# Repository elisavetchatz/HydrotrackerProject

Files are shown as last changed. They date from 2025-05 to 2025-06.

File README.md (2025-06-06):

# 💧 HydroTracker - Smart Water Cup Monitor for Cafés
<p align="center">
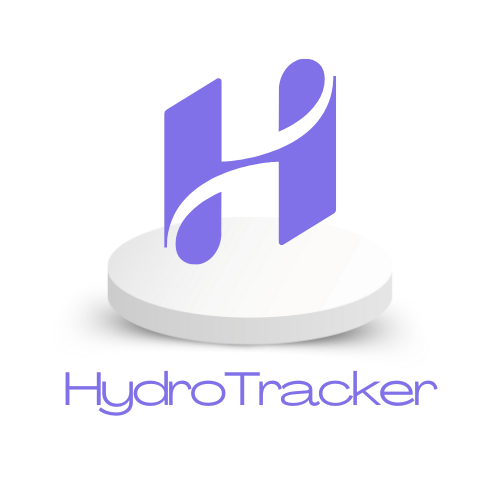
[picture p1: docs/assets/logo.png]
Hydrotracker Logo
  
</p>

HydroTracker is a smart hydration monitoring system originally designed to encourage water intake in work environments, now adapted into a **real-time service assistant** for **cafés**. It helps waitstaff **identify when customers' glasses are empty** and notifies them instantly—improving both **efficiency** and **customer experience**.

---

## 🚀 Project Overview

The idea began with a smart base (coaster) that uses a weight sensor to monitor the **daily water consumption** of users. Over time, the system evolved into a scalable solution for the **hospitality industry**, particularly cafés and restaurants.

Instead of waiters constantly checking glasses, HydroTracker lets them know **exactly when a refill is needed**, thanks to an intelligent network of coasters.

---

## 🎯 Use Case

> 💡 **Target audience**: Cafés and hospitality venues aiming to enhance service automation and hydration awareness.

Each coaster uses a **load cell sensor** connected to an **Arduino Uno** to detect changes in weight. When a glass is detected as **empty**, the node wirelessly transmits a message to a central receiver, which relays the update to a GUI system via serial communication.

---

## 🧠 Project Structure
```
📦 Hydrotracker
├── 📁 media # Videos, promo material, demo shots
│ ├── 📁 demo
│ └── 📁 promo
├── 📁 src # Main source code (Python, Arduino)
│ ├── 📁 data_processing
│ └── 📁 networking
├── 📁 docs # Documentation and reports
│ ├── 📁 assets
│   ├── 📁 gui_images
│   ├── 📁 load cell images
│   ├── 📁 setup_images
|   ├── 📁 business_images
│ └── 📁 report
├── 📁 3d_prints # 3D-printable .stl files
```
---

## 🛠️ Hardware Used

- 🧠 **Arduino Uno** – used in both nodes and central receiver  
- ⚖️ **3kg Load Cell** – detects weight of the glass  
- 🔊 **HX711 Amplifier Module** – reads and amplifies sensor output  
- 📡 **RFM22 ISM Transceiver Module** – enables node-to-node communication  
- 🧩 **Breadboard & Jumper Wires**  
- 🖨️ **3D-Printed Cup Base** – physically holds the sensor and glass  

---

## 📐 System Functionality

### 🧪 Sensor Logic

- Load cell detects the **weight** of the glass
- Readings are amplified and interpreted on the Arduino node
- If weight is below a threshold for a set time → considered **empty**

### 🔔 Notification & Communication

- Node sends signal via **ALOHA-style RF protocol**
- Central receiver aggregates messages and sends them to host PC
- The PC displays each node’s state (e.g., FULL / EMPTY) in a **GUI dashboard**
- Colored indicators show the status (e.g., 🟢 full, 🔴 empty)

---

## 📸 Media & Demo

The `media/` folder includes:
  
- 🎥 Demo video showing the system in action  
- 🖼️ Slides for presentations 
- 🎥 Promo video  

### ▶️ Watch Videos

🔧 Real-time demo of HydroTracker in action: [Demo Video](https://www.youtube.com/watch?v=DEMO_VIDEO_ID)

🎬 Promotional overview for cafés: [Promo Video](https://www.youtube.com/watch?v=PROMO_VIDEO_ID)

> Made with ☕ and 💡 by Team HydroTracker – Aristotle University of Thessaloniki

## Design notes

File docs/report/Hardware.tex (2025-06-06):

This section presents the hardware behind \textit{Hydrotracker}.  Below, we outline the materials used, the sensing principles, the mechanical base design and the full setup procedure.

\subsection{Materials Used}
The following materials were used in constructing a functional prototype of our system:
\begin{itemize}
\item \textbf{Arduino Uno board} – the central microcontroller used to read sensor data and handle communication logic.
\item \textbf{RFM22 ISM Transceiver module} – enables wireless communication between each coaster and a central receiver node.
\item \textbf{3kg Load Cell} – senses the weight of the glass placed on the coaster.
\item \textbf{HX711 Amplifier Module} – amplifies and digitizes the low-voltage analog signal from the load cell.
\item \textbf{3D-printed coaster base} – a custom mechanical housing for the sensor and load distribution.
\item \textbf{LED + 470 $\Omega $ resistor} – provides visual feedback for the taring process.
\item \textbf{Push button} – used to initiate the taring routine manually.
\end{itemize}
For the calibration procedure, we also used:
\begin{itemize}
\item A standard empty water glass.
\item A digital kitchen scale (±1 g precision).
\end{itemize}

\subsection{Load Cell}
The core of the system’s sensing capability lies in the load cell. A load cell is a transducer that converts the force (weight) applied to it into an electrical signal. When an object is placed on the load cell, it slightly deforms (Fig~\ref{fig:loadcell_deforms}). This deformation changes the electrical resistance inside the sensor (Fig~\ref{fig:loadcell-circuit-comparison}), which is then converted into a voltage signal proportional to the weight. This signal can be read by a microcontroller (e.g., Arduino) to determine how much the object weighs, up to a maximum of 3kg. In our case, the 3kg bar-type load cell is placed beneath a flat surface where the glass rests (Fig: \ref{fig:cup-base-views}) .

Since the voltage output from a load cell is very low (typically in the mV range), we use the HX711 module — a high-resolution 24-bit ADC amplifier — to digitize this signal and make it readable by the Arduino (Fig:~\ref{fig:system-setup-views}).
\begin{figure}[H]
    \centering
    \begin{subfigure}[b]{0.45\linewidth}
        \centering
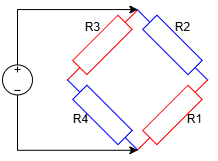
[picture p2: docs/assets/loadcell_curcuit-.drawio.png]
        
        \caption{Load cell circuit without weight}
        \label{fig:loadcell-weight}
    \end{subfigure}
    \hfill
    \begin{subfigure}[b]{0.45\linewidth}
        \centering
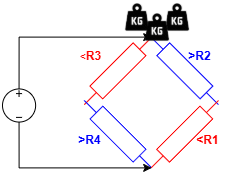
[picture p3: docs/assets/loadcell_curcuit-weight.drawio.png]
        
        \caption{Load cell circuit with weight}
        \label{fig:loadcell-noweight}
    \end{subfigure}
    \caption{Comparison of load cell circuit states: with and without applied weight}
    \label{fig:loadcell-circuit-comparison}
\end{figure}
\begin{figure}[H]
    \centering
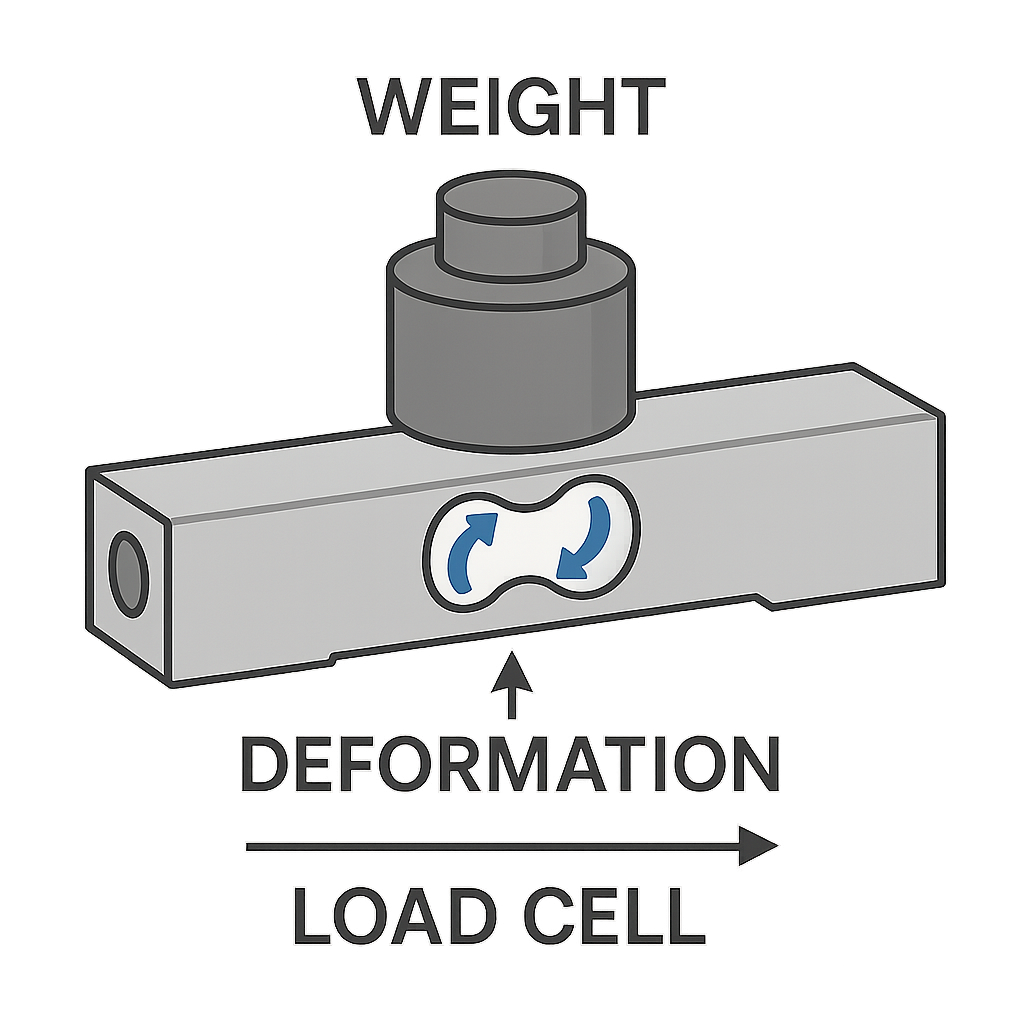
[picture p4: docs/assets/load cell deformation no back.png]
    
    \caption{Load cell slightly deformates when weight is placed on it}
    \label{fig:loadcell_deforms}
\end{figure}

\subsection{LED-Resistor-Button}
A small but essential subsystem in our design is composed of a push-button, an LED, and a 470 $\Omega$ resistor. This circuit provides user interaction and visual feedback during the taring process of the load cell.

When the system is powered on or reset, the load cell may carry residual mechanical offsets — due to the coaster’s base structure or the inherent weight of an empty cup. To correct this, we implement a manual taring mechanism, initiated by the user via the button.
The button is connected to a digital input pin on the Arduino. When pressed, it triggers the execution of a tare function. This function sets the current output of the HX711 as the new zero reference, assuming the only weight applied is that of the empty cup.

To indicate the progress of this operation, an \textit{LED} is also included. It is connected in series with a 470 $\Omega$ resistor to limit current and is wired to another digital pin configured as an output. When taring is in progress, the LED turns on. Once the process is complete, the LED switches off, notifying the user that the system is ready for use.

\subsection{3D printed cup base}
The physical housing of the coaster is critical to ensure consistent force transfer from the glass to the sensor. Our design consists of two %interlocking 
3D-printed shells (top and bottom). The upper platform is where the base of the glass rests, designed to %evenly distribute the load
concentrate the load to the edge of the load cell for maximum accuracy.
This geometry ensures that vertical force is transmitted directly through the center of the load cell, minimizing measurement noise due to tilting or off-center loading. Figures \ref{fig:base-bottom} and \ref{fig:base-side} show a bottom and a side view of the base design, with the load cell integrated.

\begin{figure}[H]
    \centering
    \begin{subfigure}[b]{0.45\linewidth}
        \centering
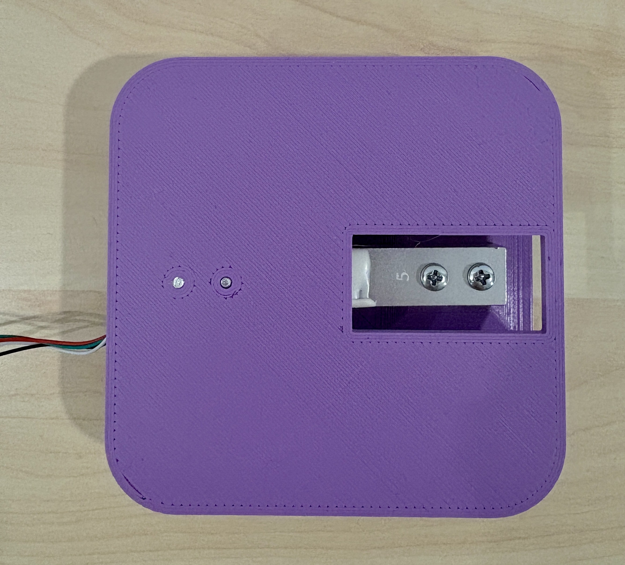
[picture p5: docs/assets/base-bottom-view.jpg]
        
        \caption{Bottom view of the cup base}
        \label{fig:base-bottom}
    \end{subfigure}
    \hfill
    \begin{subfigure}[b]{0.45\linewidth}
        \centering
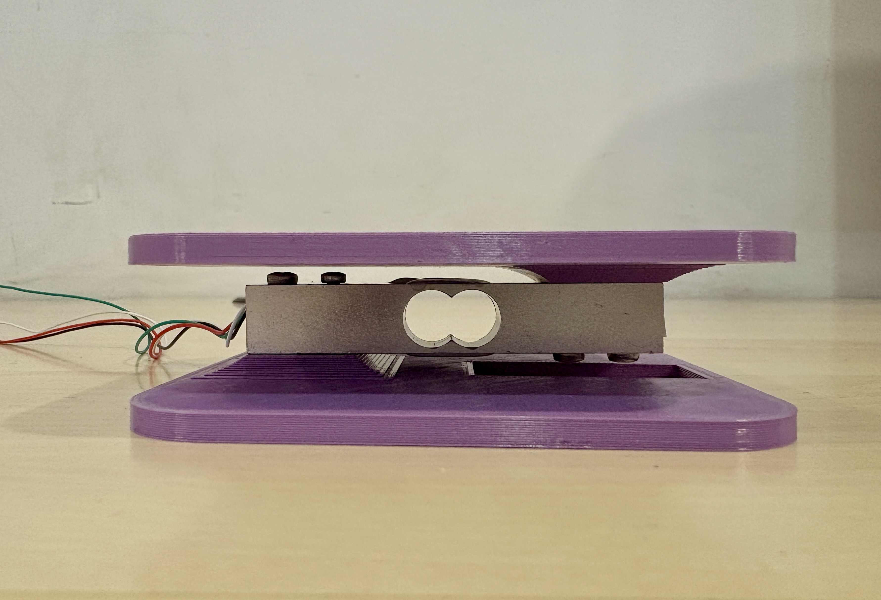
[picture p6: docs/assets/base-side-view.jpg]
        
        \caption{Side view of the cup base}
        \label{fig:base-side}
    \end{subfigure}
    \caption{3D-printed coaster base: structural views}
    \label{fig:cup-base-views}
\end{figure}

\subsection{Set-up}
The system setup consists of four primary components working together: the mechanical base, the sensing subsystem, the user interface circuit, and the wireless communication module.

The load cell is mounted securely within the custom-designed 3D-printed base. Its output is routed to the HX711 amplifier module, which is responsible for digitizing the analog signal. The HX711 is then connected to the Arduino Uno, allowing the microcontroller to receive precise weight data.

\begin{figure}[H]
    \centering
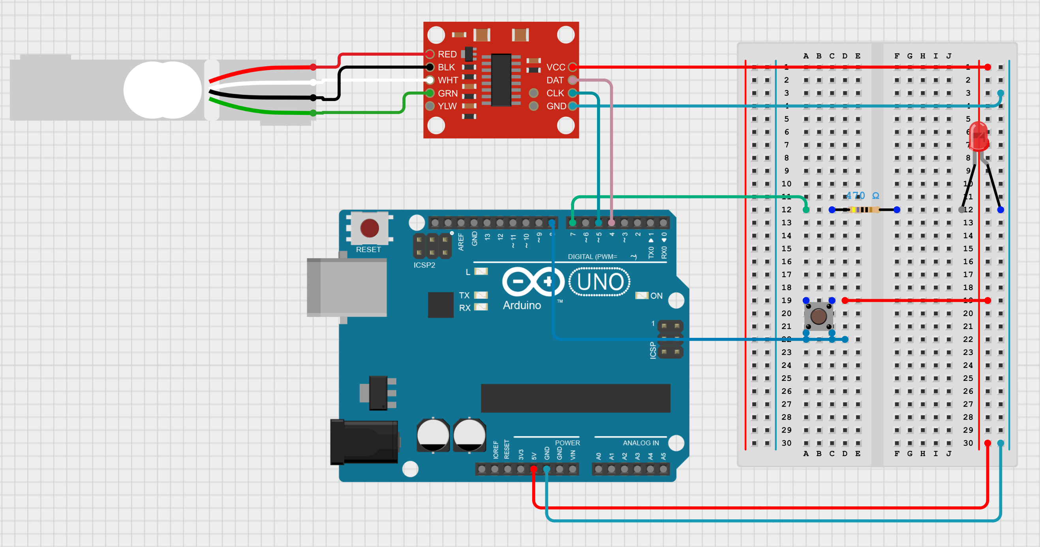
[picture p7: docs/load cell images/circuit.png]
    
    \caption{System connection diagram}
    \label{fig:circuit}
\end{figure}

On the breadboard, the push-button and LED are in series with the 470 $\Omega$ resistor. The button is connected to a digital input pin and is used to trigger the taring process, while the LED is connected to an output pin and provides visual feedback indicating the system’s readiness.

To enable communication between multiple coaster nodes and a central monitoring station, the system incorporates an RFM22 wireless transceiver, connected to the Arduino via SPI. This module transmits each node’s state information (\texttt{EMPTY}, \texttt{NOTEMPTY}, \texttt{NOTEXIST}) to a receiver, which updates the graphical user interface accordingly.

The full connection diagram of the system is displayed on Figure \ref{fig:circuit}

\begin{figure}[H]
    \centering
    \begin{subfigure}[b]{0.45\linewidth}
        \centering
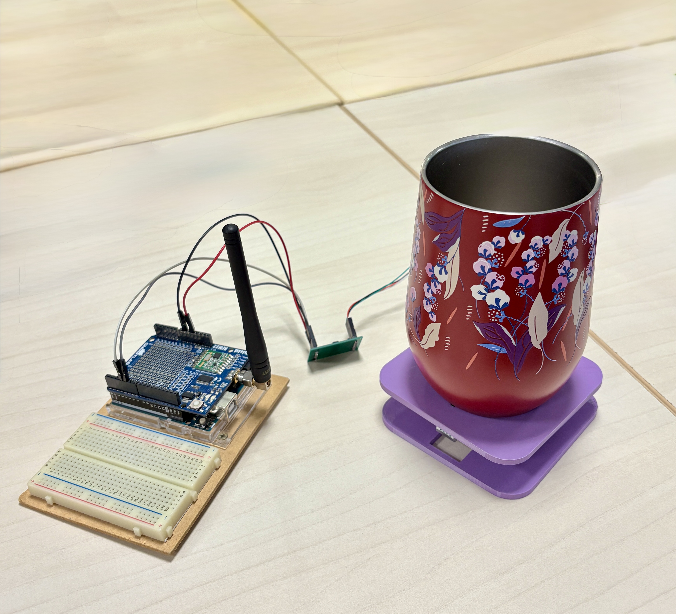
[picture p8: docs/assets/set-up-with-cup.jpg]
        
        \caption{System setup with the cup placed on the coaster}
        \label{fig:setup-with-cup}
    \end{subfigure}
    \hfill
    \begin{subfigure}[b]{0.45\linewidth}
        \centering
        
        \caption{System setup without the cup}
        \label{fig:setup-without-cup}
    \end{subfigure}
    \caption{Smart coaster hardware setup: with and without the cup}
    \label{fig:system-setup-views}
\end{figure}

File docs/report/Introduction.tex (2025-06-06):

The goal of this assignment is to design and implement a network-based application that provides real-time monitoring and communication functionalities. The system must support node-to-node interaction, dynamic data handling, and practical deployment in a real-world environment.

\subsection{HydroTracker}

\textit{HydroTracker} is a smart service-assistance system designed for use in cafés and similar settings. Its core concept is based on a distributed network of coaster-shaped sensing nodes that monitor water glass levels.

Each coaster node integrates a load cell — a force sensor that varies resistance with applied weight — connected to an Arduino Uno microcontroller. These microcontrollers act as \textbf{transmitters}, processing the weight data locally and sending it wirelessly to a central \textbf{receiver node}, also built on an Arduino. The receiver collects the measurements from all transmitters and forwards them via serial communication to a host computer. There, a data processing application interprets the input and presents it in a graphical user interface, clearly displaying the fill level of each glass using intuitive color indicators.

\begin{figure}[H]
    \centering
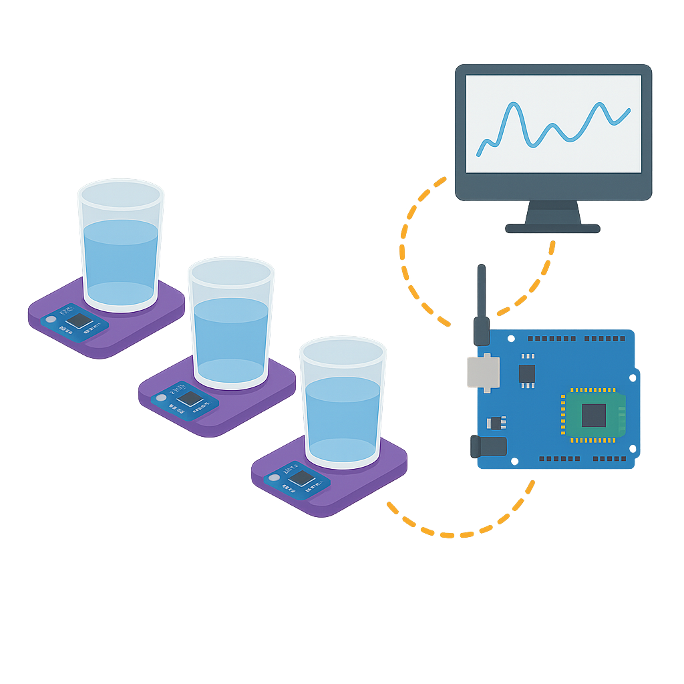
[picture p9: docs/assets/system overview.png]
    
  \caption{HydroTracker System Overview}
  \label{fig:hydrotracker_architecture}
\end{figure}

The main purpose of HydroTracker is to help waitstaff monitor tables efficiently, without having to constantly check every glass manually. This reduces unnecessary effort, streamlines service flow, and enhances the overall customer experience.

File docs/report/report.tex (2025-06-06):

\documentclass{article}
\usepackage{graphicx}
\usepackage[style=ieee]{biblatex} % Set the reference style to IEEE
\usepackage{xcolor}
\usepackage{hyperref}
\usepackage{titletoc}

\usepackage{array} % For customizing the table
\usepackage{booktabs} % For better quality horizontal lines
\usepackage{graphicx} % Package for including images
\usepackage{float}
\usepackage{subcaption}

% Define margins
\usepackage[margin=1in]{geometry}

\usepackage{listings}
\usepackage{xcolor}

\lstset{
  basicstyle=\ttfamily\footnotesize,
  numbers=left,
  numberstyle=\tiny\color{gray},
  stepnumber=1,
  numbersep=5pt,
  backgroundcolor=\color{white},
  showspaces=false,
  showstringspaces=false,
  showtabs=false,
  frame=single,
  rulecolor=\color{black},
  tabsize=2,
  captionpos=b,
  breaklines=true,
  breakatwhitespace=false,
  keywordstyle=\color{blue},
  commentstyle=\color{gray},
  stringstyle=\color{orange},
}

\begin{document}

\begin{titlepage}
    \centering
    % AUTH University logo
    
    \par\vspace{2cm}

    % University name and course details
    {\Large \textbf{Aristotle University of Thessaloniki} \par}
    \vspace{0.5cm}
    {\large School of Electrical and Computer Engineering\par}
    {\large 099 - Applications of Telecommunication Devices\par}
    \vspace{3cm}

    % Project details
    {\Large \textbf{HydroTracker} \par}
    {\large Smart cup base network \par}
    { A wireless communication system designed to \\ detect and report the water level in a glass in real time \par}
    \vspace{3cm}

    % Team members
    {\large \textbf{Team} \par}
    \vspace{0.5cm}
    \begin{tabular}{ll}
    10670 & Maria Charisi \\
    10792 & Elisavet Chatzikyrka \\
    10674 & Ioannis Lolos\\
    10866 & Maria Sotiria Kostomanolaki \\
    \end{tabular}
    \par\vspace{3cm}

    % Date
    {\today \par}

\end{titlepage}

\tableofcontents 

\newpage 

% Document content
\section{Introduction}
\input{Introduction}

\newpage
\section{Hardware}
\input{Hardware}

\section{Networking}
\input{Networking}

\section{Data Processing and User Interface}
\input{DataProcessing}

\section{Business Model}
\input{BussinessModel}

\section{Conclusion}
\input{Conclusion}

\begin{thebibliography}{9}

\bibitem{hx711-youtube}
HX711 with a Four Wire Load Cell and Arduino | Step by Step Guide., 
\textit{YouTube video}, accessed May 2025. \\
\url{https://www.youtube.com/watch?v=sxzoAGf1kOo}

\bibitem{hx711-github}
$HX711\_ADC$, 
\textit{GitHub Repository}, accessed May 2025. \\
\url{https://github.com/olkal/HX711_ADC}

\bibitem{prof-code}
Lab Starter Code – Applications of Telecommunication Devices, 
provided by Prof. [Dimitriou Antonios], AUTH, Spring 2025.

\end{thebibliography}
\textbf{Project Repository:} \url{https://github.com/elisavetchatz/HydrotrackerProject}
\end{document}

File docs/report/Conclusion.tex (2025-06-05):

HydroTracker is a smart coaster system designed to monitor the fill level of glasses in real time and notify staff when service is needed. By combining load cell sensors, Arduino-based wireless nodes, and a graphical user interface, the system offers an efficient and user-friendly solution for service environments.The system performs reliably, offering accurate state detection and real-time visual feedback. 

Ideally, HydroTracker would be implemented as a fully integrated, wireless, and portable smart device. Instead of relying on a separate Arduino board and wired modules, each coaster node would embed a compact microcontroller (e.g., ESP32) directly into its body, along with a thin rechargeable battery and low-power management for long-term operation. This integration would eliminate external components and wiring, resulting in a cleaner, more robust design. Additionally, wireless connectivity such as Wi-Fi or Bluetooth Low Energy (BLE) could support seamless data transmission and real-time monitoring across larger spaces or cloud services. Lastly, the ideal sensor for this setup would be a thinner load cell, helping reduce the overall size and visual presence of the coaster, making it more discreet, user-friendly, and visually appealing.

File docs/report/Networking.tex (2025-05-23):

The HydroTracker system utilizes a custom wireless communication network built on \textit{Arduino microcontrollers} and \textit{RFM22 ISM-band transceivers}. 
Each coaster-shaped transmitter node, associated with a water glass, continuously monitors weight data using an \textit{HX711 load cell}. 
This data is processed locally and transmitted wirelessly to a central receiver node. 
The receiver then relays this information to a host computer for real-time visualization.

In this section, we will describe the code implementation for both the receiver and transmitter nodes, and explain the wireless communication protocol used in the system.

\subsection{Wireless Communication Protocol}

The system uses the RF22Router library, which provides a basic routing layer over the RFM22 radio transceivers. 
Each transmitter node and the receiver are assigned unique addresses, enabling reliable routing and identification of messages. 
Communication operates on the \textit{444.0 MHz} frequency using \textit{Gaussian Frequency Shift Keying (GFSK)} modulation with a data rate of \textit{125 kbps}.

To manage potential transmission collisions, the system implements a simplified \textit{ALOHA protocol} in the transmitter code:
\begin{itemize}
    \item Each transmitter sends a data packet using \texttt{sendtoWait()}, which waits for an acknowledgment from the receiver.
    \item If the acknowledgment is not received (indicating a failed or collided transmission), the transmitter waits for a \textit{random backoff delay} between 200 ms and 3000 ms before retrying.
    \item This randomized retransmission reduces the chance of repeated collisions when multiple nodes attempt to send data at the same time.
\end{itemize}

\begin{lstlisting}[language=C++, caption={ALOHA protocol implementation in the transmitter}]
bool successful_packet = false;
while (!successful_packet){

    if (rf22.sendtoWait(data_send, msg_len, DESTINATION_ADDRESS) != RF22_ROUTER_ERROR_NONE)
    {
        Serial.print("Sending: ");
        Serial.println(data_read);
        long randNumber = random(200, 3000)
        delay(randNumber);
    }
    else
    {
        successful_packet = true;
        Serial.println("Packet sent successfully!");
    }
}
\end{lstlisting}

This approach is particularly suited for low-traffic, sporadic communication systems, such as HydroTracker, where nodes send updates only when state changes are detected. 

\subsection{Receiver}
The receiver node is responsible for collecting data from multiple transmitters and relaying it to the host computer.
Its primary tasks are:

\begin{itemize}
    \item Initialize the RF22 radio module.
    \item Define known routes to each transmitter node.
    \item Continuously receive incoming data packets.
    \item Format the received data as \texttt{Node <node\_id> - State: <state>}.
    \item Forward the formatted data to the host computer via serial communication for further processing and display.
\end{itemize}

\subsection{Transmitters}
Each transmitter node is responsible for monitoring the weight of an individual glass and wirelessly reporting its status to the receiver node.
The transmitter code performs the following key functions:

\begin{enumerate}
    \item \textbf{Load cell initialization:}{
    Each transmitter uses an \textit{HX711} load cell amplifier to measure the weight of the glass. 
    The initialization of the load cell is performed during the \texttt{setup()} function.
    \begin{itemize}
        \item The data and clock pins of the HX711 are defined and used to create a \texttt{HX711\_ADC} object named \texttt{LoadCell}.
        \item The \texttt{LoadCell.begin()} function initializes the connection to the sensor.
        \item The \texttt{LoadCell.start(2000, tare)} function starts the sensor with a 2-second warm-up period and performs a tare (zeroing) operation.
        \item If initialization is successful, a calibration factor is applied using \texttt{LoadCell.setCalFactor()}. This factor is determined empirically through a calibration process and converts raw readings into meaningful weight units.
    \end{itemize}

    \begin{lstlisting}[language=C++, caption={Load cell initialization}]
    #include <HX711_ADC.h>

    const int HX711_DOUT = 4; // HX711 data pin
    const int HX711_SCK = 5;  // HX711 clock pin
    HX711_ADC LoadCell(HX711_DOUT, HX711_SCK);

    void setup() {
        LoadCell.begin();
        bool tare = true;
        LoadCell.start(2000, tare);

        if (LoadCell.getTareTimeoutFlag() || LoadCell.getSignalTimeoutFlag())
        {
            Serial.println("HX711 not found. Check wiring and pin designations.");
            while (1);
        }
        else
        {
            float calibrationFactor = 448.31; // Calibration Factor
            LoadCell.setCalFactor(calibrationFactor);
        }
    }
    \end{lstlisting}}

    \item \textbf{Weight monitoring and State classification:}{
    The function \texttt{getCurrentState()} is responsible for determining the current state of the transmitter node based on the measured weight. 
    It uses predefined threshold values to classify the state of the glass as either \texttt{NOTEXIST}, \texttt{EMPTY}, or \texttt{FULL}.

    Before classification, the function ensures that the weight reading is stable by repeatedly sampling the load cell until the weight change falls within a ±1g margin.
    This is necessary because, after a change in weight, the load cell may take a few seconds to stabilize.

    The thresholds are defined based on the fact that the load cell is tared with an empty glass placed on it. 
    This implies the following:
    \begin{itemize}
        \item \textbf{Values around 0g:} The glass is empty.
        \item \textbf{Negative values:} The glass does not exist.
        \item \textbf{Positive values:} The glass contains some amount of water.
    \end{itemize}

    \begin{lstlisting}[language=C++, caption={Weight monitoring and state classification}]
    const float NOTEXIST_THRESHOLD = -20.0; // Threshold for no existence
    const float EMPTY_THRESHOLD = 50.0;    // Threshold for empty

    state getCurrentState(){

        LoadCell.update();
        float currentWeight = LoadCell.getData();

        while (1)
        {
            delay(1000);
            LoadCell.update();
            float weight = LoadCell.getData();

            if (weight < currentWeight + 1.0 && weight > currentWeight - 1.0)
            {
                currentWeight = weight;
                break; // Exit the loop if weight is stable
            }

            currentWeight = weight;
        }

        if (currentWeight < NOTEXIST_THRESHOLD) return NOTEXIST;
        else if (currentWeight < EMPTY_THRESHOLD) return EMPTY;
        else if (currentWeight >= EMPTY_THRESHOLD) return NOTEMPTY;
    }
    \end{lstlisting}}

    \item \textbf{Tare function:}{
    The user can manually tare the load cell by pressing a button connected to a digital pin.
    The tare function is triggered when the button is pressed, and it sets the current weight reading to zero.
    This is useful for recalibrating the load cell when a new glass is placed on it.
    
    \begin{lstlisting}[language=C++, caption={Tare function}]
    if (digitalRead(TARE_BUTTON_PIN) == HIGH)
    {
        Serial.println("Tare button pressed. Taring...");
        digitalWrite(LED_PIN, HIGH);
        LoadCell.tare();
        digitalWrite(LED_PIN, LOW);
    }
    \end{lstlisting}}

    \item \textbf{Data transmission:}{
    The packet transmission is handled by the \texttt{sendPacket()} function. 
    This function formats the current state as a string (e.g., \texttt{"EMPTY"}, \texttt{NOTEMPTY"}, \texttt{"NOTEXIST"}) and attempts to transmit it to the receiver node using the \textit{ALOHA protocol}.

    To optimize network usage and conserve energy, the transmitter only sends a packet when a change in the glass state is detected.
    To achieve this, in the \texttt{loop()} function, the following steps are performed:
    \begin{itemize}
        \item The transmitter maintains a record of the \texttt{previousState}.
        \item On each loop iteration, the current state is determined using \texttt{getCurrentState()}.
        \item If the state is unchanged, no packet is sent.
        \item If the state changes, the new state is sent using \texttt{sendPacket()} and \texttt{previousState} is updated accordingly.
    \end{itemize}

    \begin{lstlisting}[language=C++, caption={Packet transmission on state change}]
    state currentState = getCurrentState();

    if (currentState != previousState)
    {
        sendPacket(currentState);
        previousState = currentState;
    }
    else
    {
        Serial.print("State unchanged: ");
        Serial.println(stateToString(currentState));
    }
    \end{lstlisting}}
\end{enumerate}

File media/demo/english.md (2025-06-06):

## Demo Voiceover in English

At first, we see the coaster from a side view.
It consists of two 3D-printed bases, which enclose a variable metallic resistance — a load cell.

Placing it in a horizontal position, we observe the surface where the glass is placed.

Then, we take a look at the full wiring of the sensor.

First, we have the HX711 amplifier, which digitizes the analog signal from the load cell.
Next, we see the breadboard, where our microcontroller is connected — in this case, an Arduino Uno.

On the breadboard, there is an LED with a 470-ohm resistor and a button, used to automate the taring process.

The Arduino is also connected to an RF22 module, enabling wireless communication between the coaster nodes.

When the sensor is initialized, we observe weight measurements on the serial monitor.
Since the coaster is empty, these values fluctuate close to zero, and the default state displayed is "EMPTY".

We now place an empty glass on the coaster, with the purpose of performing a tare — zeroing the sensor using this specific glass as a tare weight.

We observe that the weight reading increases significantly — as expected.
At the same time, the state of the glass changes from "EMPTY" to "NOT EMPTY".

Due to this change, the transmitter sends a packet to the receiver, which then updates the GUI at the top right of the screen.

In order for the coaster to function correctly, the taring process must be completed first — as mentioned earlier.
We press the button to initiate the process. The LED turns on, and once the taring is complete, it turns off — indicating to the user that the system is ready for use.

After the taring, we observe on the GUI that the node now shows the correct state — "EMPTY".

Now, we fill the glass with water, and as expected, we see an immediate increase in the sensor's weight reading.

As soon as this reading exceeds a predefined threshold, the coaster’s state changes.
A new ALOHA packet is sent from the transmitter to the receiver, and the GUI updates automatically.

We now expand the network by adding another node — that is, a second glass.
This addition is immediately reflected in the GUI, as a new node label appears.

We fill the second glass with water, and observe the change in status from "EMPTY" to "NOT EMPTY".

Next, we remove the glass from the base. After a short delay, the state changes to "NOT EXIST".
During this time, the algorithm checks if the current state is significantly different from the previous ones, ensuring the change is valid before sending the update packet.

It is worth noting that the green color on the GUI indicates that the glass is not empty, and the waitress does not need to intervene.

In contrast, when the color turns red, it signals that it is time to serve the customer.

Continuing, we place the glass back on the base, and the state returns to "NOT EMPTY".

Finally, we lift the glass from the second node, which was previously full.
After consuming its contents, we place the now empty glass back on the coaster.

As expected, the coaster detects the change, the node sends a new packet, and the waitress sees on the GUI that the node has turned red, signaling that the glass is empty and the customer needs service.

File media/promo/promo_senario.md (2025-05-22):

# HydroTracker – Promo Video Scenario

## Title
**HydroTracker – Never let a glass go empty again!**

## Overview
A chaotic day in a busy café, with a frantic waiter running around trying to keep up with empty glasses, turns into a smooth and smart customer service experience thanks to **HydroTracker** – the smart coaster that alerts you when a glass is empty.

---

## Scenes & Shooting Directions

### Scene 1 – “The Chaos”

**Location:** Café with tables, customers, waiter behind the bar  
**Duration:** ~30–40 seconds  

#### Shot 1: Wide
- Waiter is behind the bar, stressed and sweaty.
- He nervously scans the tables and moves his head back and forth to ensure every water cup is full.
- Voice-over: *"In a world where every drop counts..."*

#### Shot 2: Close-Up + Slow Motion
- A customer finishes their last sip in slow motion.
- Close-up on the customer swallowing the final gulp.
- Loud *"gulp"* sound effect.
- Cut to waiter’s eyes—sharp focus and dramatic zoom as he jolts upright like an alarm just went off.

#### Shot 3: Chaos Montage
- The waiter rushes across the café.
- Spills a tray, bumps into chairs.
- Split screen: another customer finishes their water.
- The waiter is overwhelmed, always one step behind.

#### Shot 4: Time Lapse
- Fast-forward montage of the waiter running non-stop.
- Final shot: he collapses in a chair, exhausted. All glasses are still empty.

---

### Scene 2 – “The Solution”

**Location:** Same café  
**Duration:** ~30 seconds  

#### Shot 5: Logo Intro
- HydroTracker (logo) appears.
- Slogan: *"The smart coaster that does the job for you!"*

#### Shot 6: Calm Bartender
- Same waiter, now relaxed, sitting behind the bar with a coffee.
- He watches a screen (laptop) with the GUI.
- All table indicators are **green**.

#### Shot 7: Sensor Trigger
- A customer finishes their water → GUI changes from green to red.
- “Ding” sound effect plays and LED light turns red.

#### Shot 8: Chill Refill
- Waiter gets up **calmly**, grabs a water jug.
- Walks to the table **in style**.

#### Shot 9: Interaction
- The customer thanks him.
- He gives a thumbs-up to the camera.

#### Shot 10: Outro
- Logo + final slogan:
  > **HydroTracker – Never let a glass go empty again!**

---

## Equipment & Props

### Equipment
- Microphone Despoinas
- Laptop to display GUI demo

### Props
- Clear water glasses
- Water jug or bottle
- Waiter apron
- HydroTracker prototype

---

## Sound & Music

- **Scene 1:** humorous music (espresso machiatto) or under pressure
- **Scene 2:** calm music
- **Sound Effects (SFX):** "gulp", "ding", footsteps, spills

---

## Filming Checklist

- Set up café environment
- Film “chaos” sequence
- Film calm scene with HydroTracker
- Record GUI state transitions (green to red)
- Add voiceover, music, and slogan
- Final edit with logo and transitions

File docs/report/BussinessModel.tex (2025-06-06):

This section presents the proposed business model for introducing \textit{HydroTracker} to the market as a product for the service industry. It includes a Business Canvas that outlines the value proposition, key cost and revenue activities, as well as a demonstration video showing the functionality of the \textit{HydroTracker}, and a promotional video.

\subsection{Business Canvas}
The \textit{HydroTracker} is an innovative water level monitoring system designed to improve customer experience and support staff efficiency in the service industry. It enables quick and efficient refills of water, helping staff respond quickly to customer needs and avoid missed requests during peak hours. This not only improves the overall customer experience, but also supports better task coordination among staff, resulting in a less stressful work environment.

What makes \textit{HydroTracker} stand out is its ability to integrate smoothly into existing service processes. Its compatibility with PDA order management systems enhances operational efficiency while reinforcing the business’s professional image. 

The primary costs in this business model include the sourcing of sensors and micro-controllers, prototype production, software development, and promotional activities.

The target market consists of approximately 110,000 service industry businesses in Greece, with early adopters being futuristic and luxury venues aiming for premium service. In the future, cost reductions will allow expansion to small and medium-sized business owners, as well as exports. Additionally, thanks to its modular and scalable architecture, \textit{HydroTracker} can be extended beyond cafés—such as into office spaces, hospitals, or co-working environments—offering smart hydration 

\begin{figure}[H]
    \centering
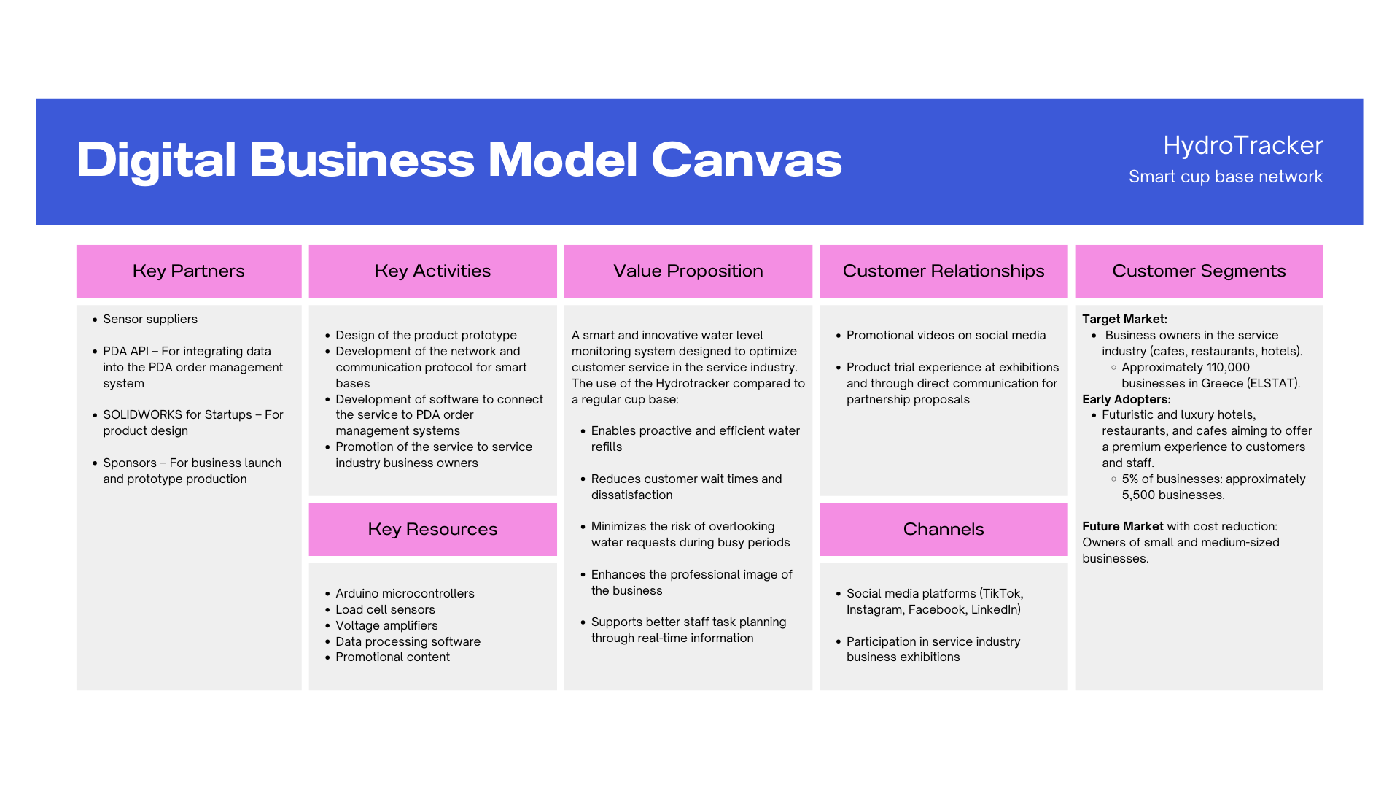
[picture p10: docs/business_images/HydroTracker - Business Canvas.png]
    
    \caption{\textit{HydtroTracker} Business Canvas}
    \label{fig:enter-label}
\end{figure}

\subsection{Demonstration Video}
A demonstration video showcasing the functionality of the \textit{HydroTracker} is available \href{https://youtu.be/DthdfglUvXY?si=8oIWrk7Wovcrerfg}{here}. The video presents how the system operates in a real-world setting, highlighting its key features.

\subsection{Promotional Video}
A promotional video has been created to highlight the key benefits of the HydroTracker for potential customers and investors. The video is available \href{https://www.youtube.com/watch?v=uHeOhnM9qX0}{here}.

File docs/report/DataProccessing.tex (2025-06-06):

In this section, we describe the software architecture of the HydroTracker system, which monitors the status of multiple sensor nodes in real time. The application is composed of two primary components:
\begin{itemize}
    \item A background thread that reads and processes incoming serial data.
    \item A user interface that visualizes node states in real-time using colored labels.
\end{itemize}

\subsection{Reading from the Serial}

Serial communication is handled by the \texttt{SerialReaderThread} class, which operates in a separate background thread to prevent GUI blocking. Its main functionality is found in the \texttt{read\_serial()} method. The thread checks if data is available (\texttt{in\_waiting > 0}), reads and decodes the incoming string, and logs it. If the message follows the format \texttt{Node<id> - State:<STATE>}, the node ID and state are extracted. This call delegates the responsibility of updating the GUI to the main application \texttt{HydrotrackerMonitor}.

\subsection{Data Processing}
Once a valid line is received, it is parsed into two key components:
\begin{itemize}
    \item \texttt{node\_id}: the identifier of the node
    \item \texttt{state}: the reported status (e.g., "EMPTY", "NOTEMPTY", or "NOTEXIST")
\end{itemize}
After extracting these, the GUI is updated only if the state has changed. Each node has an entry in a dictionary \texttt{node\_states} that keeps track of its most recent state. This structure enables efficient state tracking and minimizes unnecessary GUI updates.

The following snippet illustrates the logic used to parse incoming serial messages and trigger GUI updates accordingly:
\begin{lstlisting}[language=Python, caption={Serial data parsing and GUI update}]
if self.serial_conn.in_waiting > 0:
    # Read incoming serial line
    line = self.serial_conn.readline().decode('utf-8').strip()
    
    # Check if it matches the expected format
    if line.startswith("Node") and " - State: " in line:
        before, _, after = line.partition(" - State:")
        node_id_str = before.replace("Node", "").strip()
        state = after.strip()
        
        # If valid node ID, update the GUI
        if node_id_str.isdigit():
            self.app.update_node_state(int(node_id_str), state)
\end{lstlisting}

\subsection{User Interface}
The GUI is created using Python's \texttt{tkinter} module and is managed by the \texttt{HydrotrackerMonitor} class. For each detected node, a label is dynamically added with the method \texttt{create\_gui\_label(node\_id)}. Each label changes its color and text based on the node's current state. This is managed in the \texttt{update\_gui\_loop()} method, which periodically refreshes the display.
The following listing illustrates this logic:

\begin{lstlisting}[language=Python, caption={GUI update and label coloring based on node state}]
def update_gui_loop(self):
    for node_id, state in self.node_states.items():
        label = self.labels[node_id]
        label.config(text=f"Node {node_id}: {state}") 

        if state == "EMPTY":
            label.config(bg="#e74c3c", fg="white")  # red
        elif state == "NOTEMPTY":
            label.config(bg="#2ecc71", fg="white")  # green
        elif state == "NOTEXIST":
            label.config(bg="#7f8c8d", fg="white")  # gray
        else:
            label.config(bg="#bdc3c7", fg="black")  # default

    self.root.after(UPDATE_INTERVAL, self.update_gui_loop)
\end{lstlisting}

The following figures present the graphical user interface (GUI) of the HydroTracker system during runtime. The interface dynamically updates based on real-time input from the sensor nodes. Each label represents a specific node and changes color and text to reflect its current state. The visual encoding allows the user to quickly identify which tables require attention.

\begin{figure}[H]
    \centering
    \begin{subfigure}[b]{0.4\linewidth}
        \centering
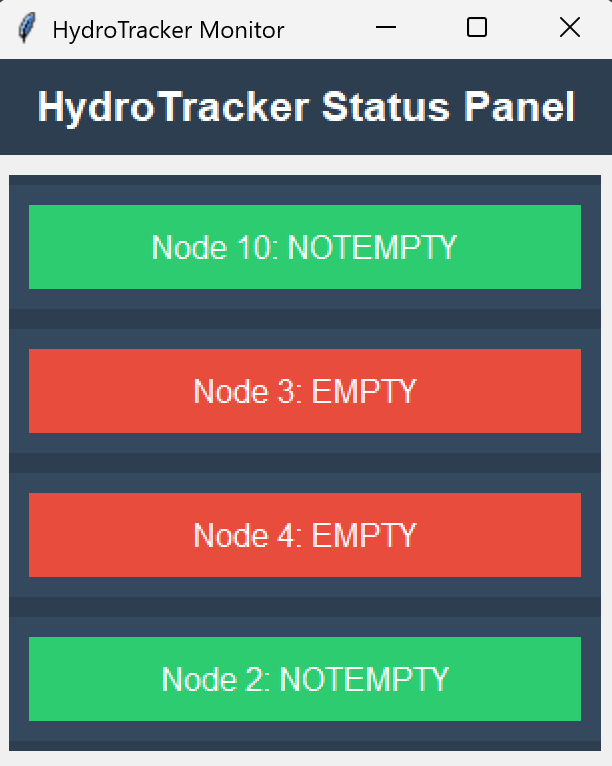
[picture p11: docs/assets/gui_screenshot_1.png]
        
        \caption{Instance of GUI}
        \label{fig:subfig1}
    \end{subfigure}
    \hfill
    \begin{subfigure}[b]{0.4\linewidth}
        \centering
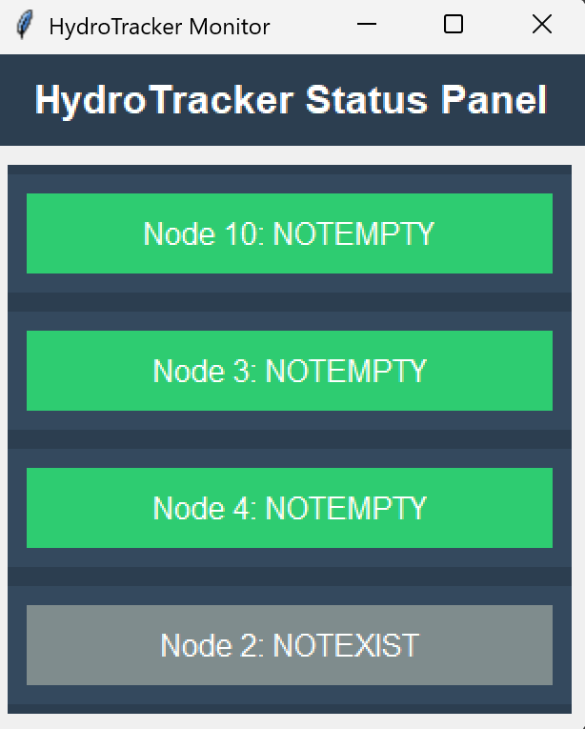
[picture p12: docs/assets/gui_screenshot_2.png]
        
        \caption{Instance for GUI}
        \label{fig:subfig2}
    \end{subfigure}
\caption{Graphical interface of HydroTracker displaying node states. Left: all nodes active. Right: one node marked as NOTEXIST.}
    \label{fig:combined}
\end{figure}

%\begin{figure}[H]
    %\centering
    %\includegraphics[width=0.3\linewidth]%{gui_images/flowchart_datapro.png}
    %\caption{Enter Caption}
    %\label{fig:enter-label}
%\end{figure}

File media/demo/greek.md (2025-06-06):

## Demonstration Video Link
[Demo Link here - greek voiceover](https://youtu.be/DthdfglUvXY?si=8oIWrk7Wovcrerfg)

## Demo Voiceover in Greek

- Αρχικά, βλέπουμε το σουβέρ από πλάγια όψη.
Πρόκειται για δύο 3D printed βάσεις, οι οποίες περικλείουν μία μεταβαλλόμενη μεταλλική αντίσταση τύπου load cell.
Τοποθετώντας το σε οριζόντια θέση, παρατηρούμε την επιφάνεια όπου τοποθετείται το ποτήρι.
Στη συνέχεια, παρατηρούμε ολόκληρη τη συνδεσμολογία του αισθητήρα.
Αρχικά, έχουμε τον ενισχυτή HX711, ο οποίος ψηφιοποιεί το αναλογικό σήμα από το load cell.
Έπειτα βλέπουμε το breadboard, όπου συνδέεται ο μικροελεγκτής — ένα Arduino Uno.
Πάνω στο breadboard υπάρχει ένα LED με μια αντίσταση 470 ohm και ένα κουμπί, τα οποία χρησιμοποιούνται για την αυτοματοποίηση της διαδικασίας του taring.
Το Arduino είναι συνδεδεμένο με μία RF22 κάρτα, η οποία επιτρέπει την ασύρματη επικοινωνία μεταξύ των κόμβων — των σουβέρ.
Κατά την αρχικοποίηση του αισθητήρα, βλέπουμε στη σειριακή είσοδο μετρήσεις βάρους.
Καθώς το σουβέρ είναι άδειο, οι τιμές αυτές κυμαίνονται κοντά στο μηδέν, και η προεπιλεγμένη ένδειξη είναι "EMPTY".

- Τοποθετούμε τώρα πάνω στο σουβέρ ένα άδειο ποτήρι, με σκοπό να κάνουμε tare — δηλαδή να μηδενίσουμε τον αισθητήρα με το συγκεκριμένο ποτήρι ως απόβαρο.
Παρατηρούμε ότι η ένδειξη του βάρους αυξάνεται σημαντικά — κάτι αναμενόμενο.
Ταυτόχρονα, η κατάσταση του ποτηριού αλλάζει από "EMPTY" σε "NOT EMPTY".
Λόγω αυτής της μεταβολής, ο transmitter στέλνει ένα πακέτο στον receiver, ο οποίος ανανεώνει αυτόματα τη γραφική διεπαφή (GUI) επάνω δεξιά στην οθόνη.
Για να λειτουργήσει σωστά το σουβέρ, πρέπει — όπως προείπαμε — να προηγηθεί η διαδικασία taring.
Πιέζουμε λοιπόν το κουμπί, το οποίο ενεργοποιεί τη διαδικασία. Το LED ανάβει, και μόλις ο μηδενισμός ολοκληρωθεί, το LED σβήνει για να ενημερώσει τον χρήστη ότι το σύστημα είναι έτοιμο προς χρήση.
Αφού ολοκληρωθεί το taring, βλέπουμε στο GUI ότι ο κόμβος εμφανίζεται πλέον με τη σωστή του κατάσταση: "EMPTY".

- Τώρα γεμίζουμε το ποτήρι με νερό και, όπως αναμενόταν, παρατηρούμε άμεση αύξηση στη μέτρηση του αισθητήρα βάρους.
Μόλις η μέτρηση ξεπεράσει ένα προκαθορισμένο όριο (threshold), η κατάσταση του σουβέρ αλλάζει.
Ένα νέο πακέτο ALOHA αποστέλλεται από τον πομπό στον δέκτη και το GUI ενημερώνεται αυτόματα.

- Προχωράμε τώρα στον εμπλουτισμό του δικτύου, προσθέτοντας έναν ακόμα κόμβο — δηλαδή ένα δεύτερο ποτήρι.
Η προσθήκη αυτή αποτυπώνεται άμεσα στο GUI, καθώς εμφανίζεται ένα νέο label κόμβου.
Γεμίζουμε το δεύτερο ποτήρι με νερό και βλέπουμε την αλλαγή της κατάστασης από "EMPTY" σε "NOT EMPTY".

- Στη συνέχεια, αφαιρούμε το ποτήρι από τη βάση. Μετά από ένα σύντομο χρονικό διάστημα, η κατάσταση αλλάζει σε "NOT EXIST".
Κατά τη διάρκεια αυτών των δευτερολέπτων, ο αλγόριθμος ελέγχει αν η τρέχουσα κατάσταση του σουβέρ διαφέρει ουσιαστικά από τις προηγούμενες, ώστε να επιβεβαιωθεί η αλλαγή και να σταλεί σωστά το πακέτο ενημέρωσης.
Αξίζει να σημειωθεί ότι το πράσινο χρώμα στο GUI υποδηλώνει ότι το ποτήρι δεν είναι άδειο και η σερβιτόρα δεν χρειάζεται να παρέμβει.

- Συνεχίζοντας, τοποθετούμε ξανά το ποτήρι στη βάση και η ένδειξη επιστρέφει στην κατάσταση "NOT EMPTY".

- Τέλος, σηκώνουμε το ποτήρι από τον δεύτερο κόμβο, το οποίο προηγουμένως ήταν γεμάτο.

- Αφού καταναλώσουμε το περιεχόμενό του, τοποθετούμε το πλέον άδειο ποτήρι πίσω στο σουβέρ.

- Όπως ήταν αναμενόμενο, το σουβέρ ανιχνεύει την αλλαγή, ο κόμβος στέλνει νέο πακέτο και η σερβιτόρα βλέπει στο GUI ότι το χρώμα του κόμβου έχει γίνει κόκκινο, πράγμα που σημαίνει ότι το ποτήρι έχει αδειάσει και ήρθε η ώρα για εξυπηρέτηση.

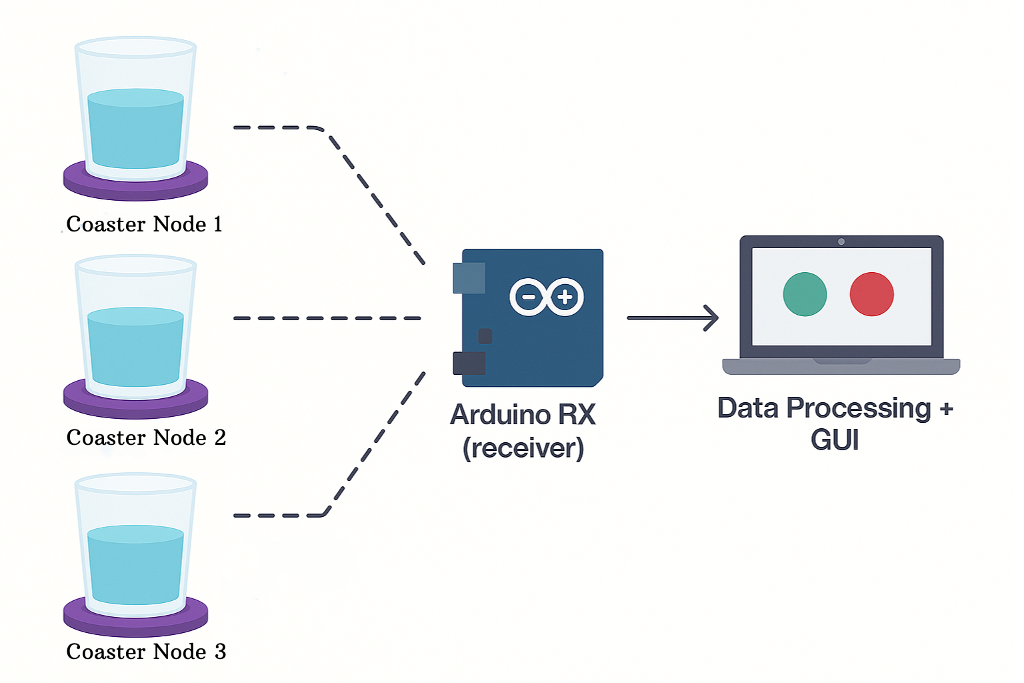
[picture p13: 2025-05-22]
docs/assets/Arduino TX.png

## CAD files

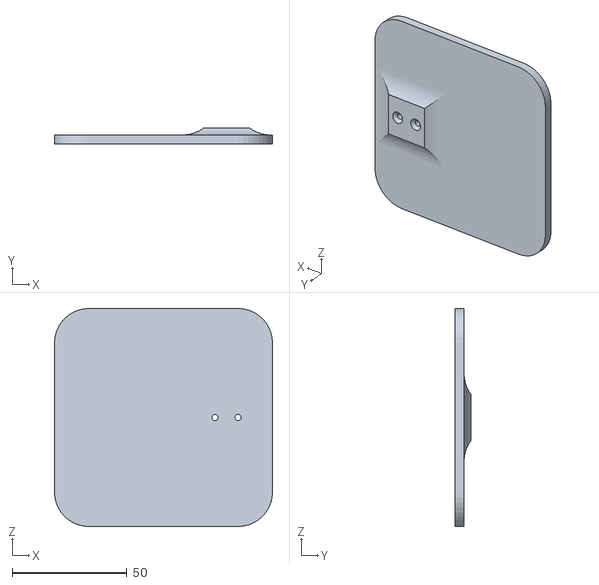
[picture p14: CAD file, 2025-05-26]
3d_prints/load_cell_support_top.STL
95.0 x 7.00 x 95.0

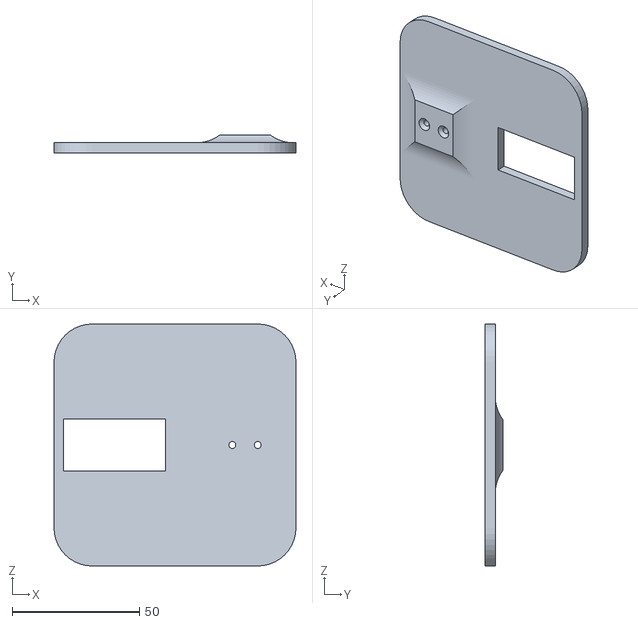
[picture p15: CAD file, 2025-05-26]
3d_prints/load_cell_support_bottom.STL
95.0 x 7.00 x 95.0

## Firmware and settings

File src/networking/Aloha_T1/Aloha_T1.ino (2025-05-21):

#include <HX711_ADC.h>
#include <RF22.h>
#include <RF22Router.h>

#define MY_ADDRESS 1
#define DESTINATION_ADDRESS 25
#define FREQUENCY 444.0
RF22Router rf22(MY_ADDRESS);

const int HX711_DOUT = 4; // HX711 data pin
const int HX711_SCK = 5;  // HX711 clock pin
HX711_ADC LoadCell(HX711_DOUT, HX711_SCK);

const float NOEXIST_THRESHOLD = -20.0; // Threshold for no existence
const float EMPTY_THRESHOLD = 50.0;    // Threshold for empty

const int TARE_BUTTON_PIN = 8; // Pin for tare button
const int LED_PIN = 7;         // Pin for LED

enum state
{
    NOEXIST,
    EMPTY,
    FULL
};

state previousState = NOEXIST;

const char *stateToString(state s)
{
    switch (s)
    {
    case NOEXIST:
        return "NOTEXIST";
    case EMPTY:
        return "EMPTY";
    case FULL:
        return "NOTEMPTY";
    default:
        return "UNKNOWN";
    }
}

state getCurrentState()
{

    LoadCell.update();
    float currentWeight = LoadCell.getData();
    Serial.print("Measured Weight: ");
    Serial.println(currentWeight);

    while (1)
    {
        delay(1000);
        LoadCell.update();
        float weight = LoadCell.getData();

        Serial.print("Measured Weight: ");
        Serial.println(weight);

        if (weight < currentWeight + 1.0 && weight > currentWeight - 1.0)
        {
            currentWeight = weight;
            break; // Exit the loop if weight is stable
        }

        currentWeight = weight;
    }

    if (currentWeight < NOEXIST_THRESHOLD)
    {
        return NOEXIST;
    }
    else if (currentWeight < EMPTY_THRESHOLD)
    {
        return EMPTY;
    }
    else if (currentWeight >= EMPTY_THRESHOLD)
    {
        return FULL;
    }

    return NOEXIST;
}

void sendPacket(state currentState)
{
    // Prepare the data to be sent - Format: <state>
    char data_read[RF22_ROUTER_MAX_MESSAGE_LEN];
    uint8_t data_send[RF22_ROUTER_MAX_MESSAGE_LEN];
    memset(data_read, '\0', sizeof(data_read));
    memset(data_send, '\0', sizeof(data_send));

    const char *stateStr = stateToString(currentState);
    sprintf(data_read, "%s", stateStr);
    uint8_t msg_len = strlen(data_read) + 1;
    memcpy(data_send, data_read, msg_len);

    // Aloha protocol implementation
    bool successful_packet = false;
    while (!successful_packet)
    {

        if (rf22.sendtoWait(data_send, msg_len, DESTINATION_ADDRESS) != RF22_ROUTER_ERROR_NONE)
        {
            Serial.print("Sending: ");
            Serial.println(data_read);
            long randNumber = random(200, 3000);
            delay(randNumber);
        }
        else
        {
            successful_packet = true;
            Serial.println("Packet sent successfully!");
        }
    }
}

void setup()
{
    Serial.begin(9600);

    pinMode(TARE_BUTTON_PIN, INPUT);
    pinMode(LED_PIN, OUTPUT);
    digitalWrite(LED_PIN, LOW);

    if (!rf22.init())
        Serial.println("RF22 init failed");
    if (!rf22.setFrequency(FREQUENCY))
        Serial.println("setFrequency Fail");
    rf22.setTxPower(RF22_TXPOW_20DBM);
    rf22.setModemConfig(RF22::GFSK_Rb125Fd125);
    rf22.addRouteTo(DESTINATION_ADDRESS, DESTINATION_ADDRESS);

    LoadCell.begin();
    bool tare = true;
    LoadCell.start(2000, tare);

    if (LoadCell.getTareTimeoutFlag() || LoadCell.getSignalTimeoutFlag())
    {
        Serial.println("HX711 not found. Check wiring and pin designations.");
        while (1)
            ;
    }
    else
    {
        float calibrationFactor = 448.31; // TODO: Set the calibration factor
        LoadCell.setCalFactor(calibrationFactor);
    }

    randomSeed(MY_ADDRESS);
}

void loop()
{

    if (digitalRead(TARE_BUTTON_PIN) == HIGH)
    {
        Serial.println("Tare button pressed. Taring...");
        digitalWrite(LED_PIN, HIGH);
        LoadCell.tare();
        digitalWrite(LED_PIN, LOW);
    }
    state currentState = getCurrentState();

    if (currentState != previousState)
    {
        sendPacket(currentState);
        previousState = currentState;
    }
    else
    {
        Serial.print("State unchanged: ");
        Serial.println(stateToString(currentState));
    }

    delay(1000); // Delay between packets
}

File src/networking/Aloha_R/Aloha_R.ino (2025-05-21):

#include <RF22.h>
#include <RF22Router.h>

#define MY_ADDRESS 25
#define NODE_ADDRESS_1 1
#define NODE_ADDRESS_2 2
#define FREQUENCY 444.0
RF22Router rf22(MY_ADDRESS);


void setup() {
    Serial.begin(9600);

    if (!rf22.init())
        Serial.println("RF22 init failed");
    if (!rf22.setFrequency(FREQUENCY))
        Serial.println("setFrequency Fail");
    rf22.setTxPower(RF22_TXPOW_20DBM);
    rf22.setModemConfig(RF22::GFSK_Rb125Fd125);

    rf22.addRouteTo(NODE_ADDRESS_1, NODE_ADDRESS_1);
    rf22.addRouteTo(NODE_ADDRESS_2, NODE_ADDRESS_2);

}

void loop() {
    uint8_t buf[RF22_ROUTER_MAX_MESSAGE_LEN];
    memset(buf, '\0', sizeof(buf));
    uint8_t len = sizeof(buf);
    uint8_t from;

    if (rf22.recvfromAck(buf, &len, &from)) {
        // Format: Node <node_id> - State: <state>
        buf[len - 1] = '\0';
        Serial.print("Node ");
        Serial.print(from);
        Serial.print(" - State: ");
        Serial.println((char*)buf);
    }
}

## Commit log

2025-05-05 Add logging functionality and integrate with HydrotrackerMonitor and serial_reader; also integrate serial reader thread
2025-05-08 Enhance GUI appearance by updating window title and adding a status panel; improve node label layout with frames
2025-05-14 Calibration base logic
2025-05-14 add calibration sketch and add averaging approach in comments
2025-05-14 Add calibration notes for HX711 Load Cell setup and usage
2025-05-21 Add button and LED for taring
2025-05-26 add 3d files
    [load_cell_support_bottom.STL, load_cell_support_top.STL]
